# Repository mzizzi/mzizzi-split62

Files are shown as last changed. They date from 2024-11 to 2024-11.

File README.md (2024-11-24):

# split62

My take on a low profile split keyboard. 

* [x] Low profile choc 1350 switches
* [x] Hot swappable
* [x] Split layout
* [x] Ortholinear
* [x] Column staggered

This was a really rewarding project and I learned a bunch along the way! I hope that this 
repo and documentation help you build your own. That said...

**Disclaimer:** While the keyboard is working while I type out this readme, there may be 
errors and/or poorly designed componetents throughout this repository. Use these files 
at your own risk. Please also read through the [TODO](#TODO) section before deciding to 
use anything in this repository.

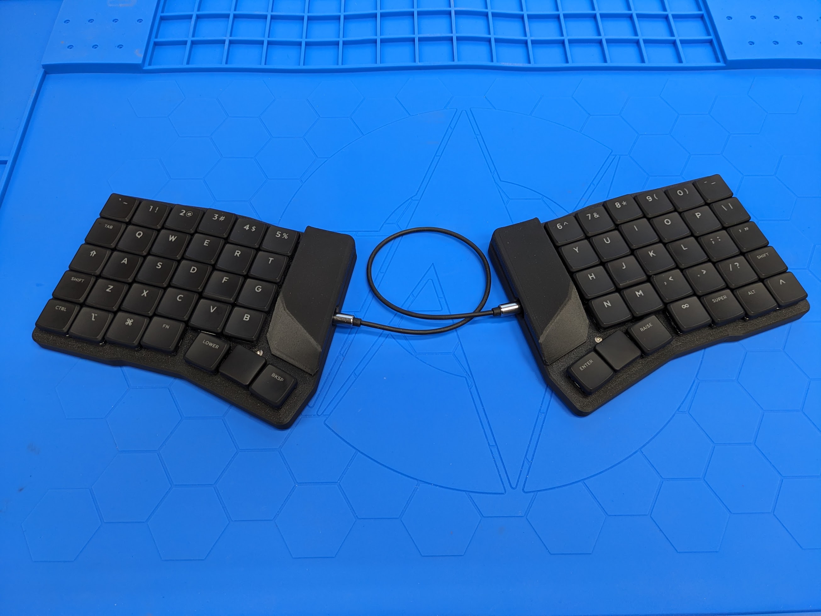
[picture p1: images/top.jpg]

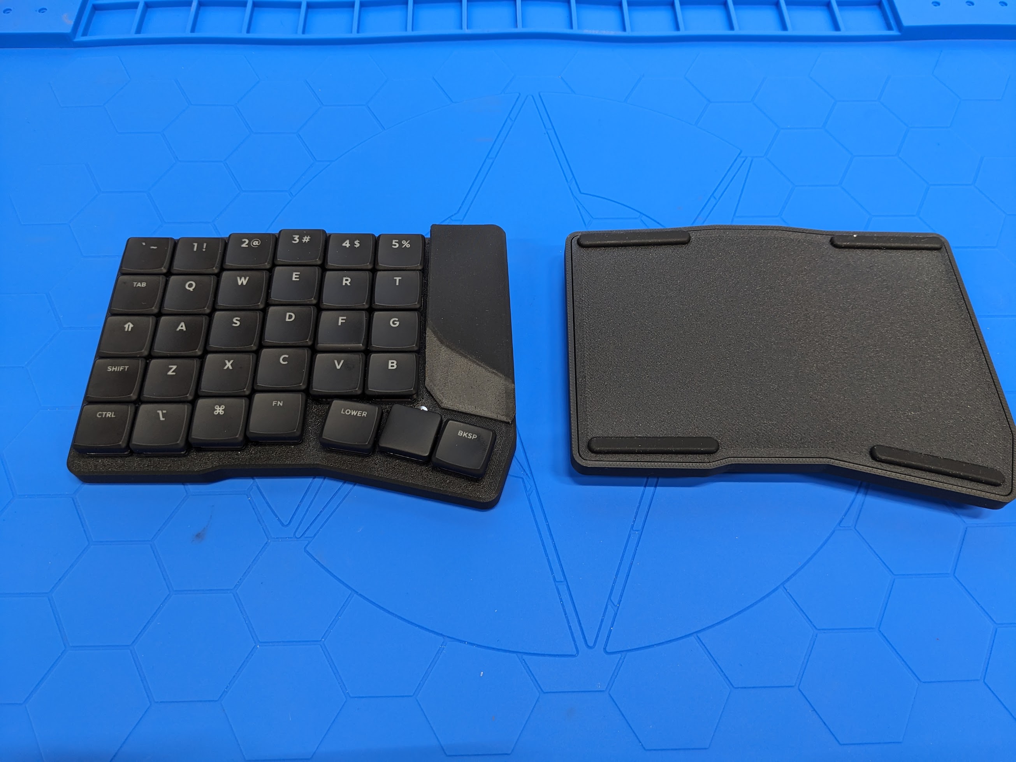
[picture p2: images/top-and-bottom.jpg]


## Firmware

This keyboard's firmware is built using QMK.

[Set up QMK](https://docs.qmk.fm/newbs_getting_started) locally and copy `qmk/keyboards/mzizzi`
 from this repository into your local qmk keyboards directory.

Connect one half of the keyboard and put the elite-pi into bootloader mode. keeb.io has excellent 
documentation on flashing firmware to the elite-pi: https://docs.keeb.io/elite-pi-guide#flashing

Enter bootloader mode (use one of the following methods):
* For a new Elite-Pi out of the packaging, it will already start in bootloader mode when plugged 
  into the computer
* Hold the Boot button (the left button) down, while pluging in the USB-C cable
* Wait for OS to detect the Elite-Pi. It will show up as a USB mass-storage device named RPI-RP2.

After the initial flash of the board you can simply hold down top innermost key (5 or 6 depending 
on the hand) while plugging in the elite-pi to make it connect in bootloader mode.

Each half of the keyboard must be flashed separately with qmk 
[handedness](https://docs.qmk.fm/features/split_keyboard#handedness-by-eeprom) flags specifying 
which side is being flashed. Both halves must be flashed:

```
qmk flash -kb mzizzi/split62 -km via -bl uf2-split-left
or
qmk flash -kb mzizzi/split62 -km via -bl uf2-split-right
```

## Configuration with via

This keyboard's firmware is compiled with support for [VIA](https://www.caniusevia.com/) which 
will allow for the keymap to be modified on the fly. The 
[via documentation](https://www.caniusevia.com/docs/specification) covers everything needed to 
get via working with the split62.

* Flash the keyboard via the instructions in this readme.
* Open https://usevia.app/ in your web browser
* Enable design mode in via settings
* Upload `qmk/keyboards/mzizzi/split62/via.json` in the design tab
* Authorize via access to the device
* Start customizing!                                                                                  |

## PCB

The PCB for this board was designed with [ergogen](https://ergogen.xyz/). I highly recommend
reading the [flatfootfox ergogen introducution](https://flatfootfox.com/ergogen-introduction/)
if you're looking to modify this board or make your own.

The PCB for this keyboard is reversible to cut down on cost of having it manufactured. Most board
manufacturers have a minimum order quantity per design (5 boards for jlcpcb). This makes for an 
interesting footprint for the elite-pi. The board is marked on either side to try and make it 
harder to accidentally install the controller socket on the wrong side.

All of the gerber files that I used to order these boards are included in the `gerbers` directory. 
Please read the [TODO](#TODO) section below before deciding whether or not to use these 
files as-is.

## Case

The case for the split62 is 3d printed. The outter shell of the case also serves as a key-plate to 
lock the choc switches into position. Ergogen is not used to generate the stls for the case.
Instead ergogen is used to generate dxfs for a "keyplate" outline. I imported that outline into
another CAD program and used it as a starting point to model the case. I printed the case on a 
bambulab x1c with 0.2mm layer height using 
[Overture matte black PLA](https://www.amazon.com/gp/product/B089S2QDHD)

## Bill of Materials

I built this keyboard for around $200 but also have a bunch of spare parts left over. 
[keeb.io](https://keeb.io/) links because they're awesome and did same day order+pickup for 
components that weren't even listed on their site!

| Item | Count | Cost | Notes |
| --- | ----- | --- | --- |
| 5x PCB | 5 | $21.00  | Only 2x needed. 5x minimum order from JLCPCB |
| 3D Printed Cases | 1 | $5.00 | Probably less if you have a printer (or know someone with a printer!) |
| Elite-Pi Controllers | 2 | $26.00  | [https://keeb.io/products/elite-pi-usb-c-pro-micro-replacement-rp2040](https://keeb.io/products/elite-pi-usb-c-pro-micro-replacement-rp2040) |
| Controller sockets | 2 | $10.00  | Not required but recommended: [https://www.amazon.com/gp/product/B07H3SK179](https://www.amazon.com/gp/product/B07H3SK179) |
| Kailh 1350 switches | 62 | $38.00  | [https://keeb.io/products/kailh-choc-low-profile-switches-v1](https://keeb.io/products/kailh-choc-low-profile-switches-v1) |
| Kailh 1350 sockets | 62 | $16.00  | [https://www.amazon.com/100Pieces-Chocolate-Switches-Accessories-Mechanical-PC/dp/B0CPVJLMDJ](https://www.amazon.com/100Pieces-Chocolate-Switches-Accessories-Mechanical-PC/dp/B0CPVJLMDJ) |
| 1N4148 SMT SOD-123 Diodes | 62 | $10.00  | [https://www.amazon.com/gp/product/B09DR5KFXM](https://www.amazon.com/gp/product/B09DR5KFXM) |
| PJ-320A TRRS jacks | 2 | $1.00 | [https://keeb.io/products/trrs-jack-3-5mm](https://keeb.io/products/trrs-jack-3-5mm) |
| Choc 1350 Keycaps | 62 | $54.00  | [https://keeb.io/products/mbk-glow-r2-choc-keycap-set](https://keeb.io/products/mbk-glow-r2-choc-keycap-set) |
| TRRS Cable | 1 | $4.00 | [https://keeb.io/products/trrs-cable?variant=50550149190](https://keeb.io/products/trrs-cable?variant=50550149190) |
| m2 screws | 8 | $7.00 | [https://www.amazon.com/Countersunk-DIN7991-Stainless-Threaded-Fasteners/dp/B0CG1PDBWN](https://www.amazon.com/Countersunk-DIN7991-Stainless-Threaded-Fasteners/dp/B0CG1PDBWN) |
| m2 threaded inserts | 8 | $8.00 | [https://www.amazon.com/gp/product/B0B8GN63S2](https://www.amazon.com/gp/product/B0B8GN63S2) |
| Rubber feet | 8 | $3.00 | [https://keeb.io/products/skuf-silicone-rubber-keyboard-feet](https://keeb.io/products/skuf-silicone-rubber-keyboard-feet) |
| Total | | $203 | 

## TODO

* Put the trrs jack closer to the side of the board. I had to cut away a few millimeters of the 
  board with a rotary tool so that the trrs connector had clearance to be fully inserted.
* Double check the trace size for 3v3 power and ground over the trrs cable. I used whatever the 
  default was without looking into how much power the rp2040 consumes. Google says that the rp2040 
  draws 20mA peak.
* More mounting holes on the PCB. A few more wouldn't hurt and would help with any warping of the
  3d printed case.
* Pull the sides of the PCB in a few mm. I didn't account for the case adding another 1-2mm.
* A better way to attach the MCU cover. This was an afterthought in v1 and attached with 
  double sided foam tape.
* Optional tenting mounts for the base of the case.
* Aluminum case

## Helpful Resources

Links to pages that helped me along the way:

* An excellent guide on using ergogen: https://flatfootfox.com/ergogen-introduction/
* qmk's documentation on a keyboard matrix and how it works:
  https://docs.qmk.fm/how_a_matrix_works
  * This article is what really made it stick for me: 
    https://www.dribin.org/dave/keyboard/one_html/
* The qmk hand wiring guide is a good introduction what you will later design a 
  pcb for: https://docs.qmk.fm/hand_wire 
* Matrix configuration: https://docs.qmk.fm/porting_your_keyboard_to_qmk#matrix-configuration
* Split keyboard layout marco: https://docs.qmk.fm/features/split_keyboard#layout-macro
* via: https://www.caniusevia.com/docs/specification

## More pictures
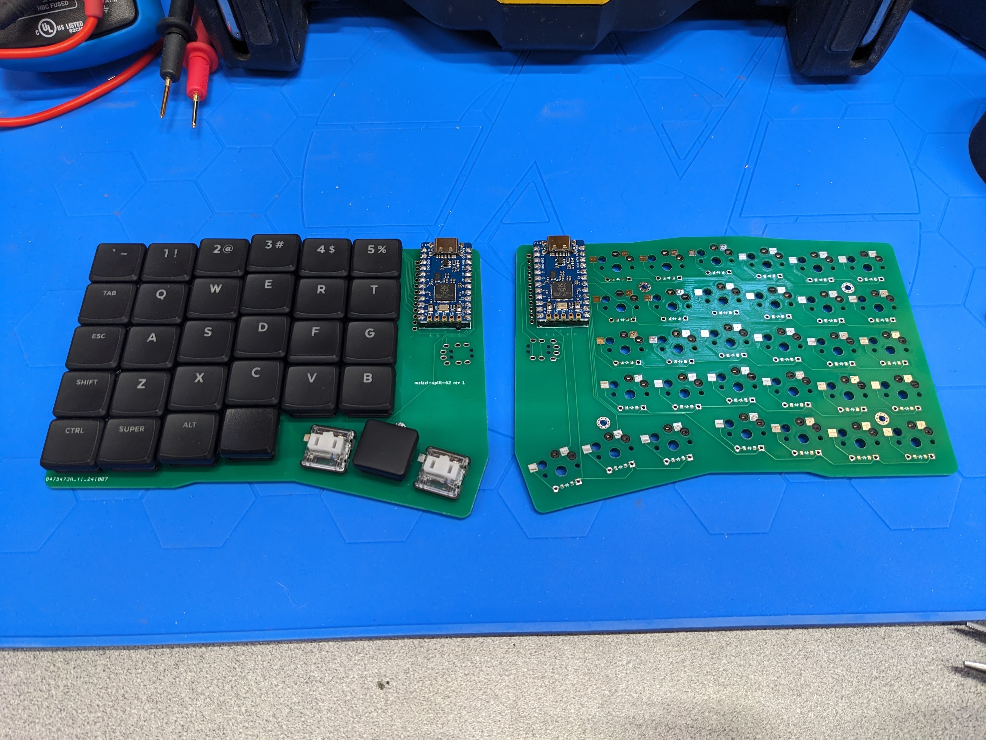
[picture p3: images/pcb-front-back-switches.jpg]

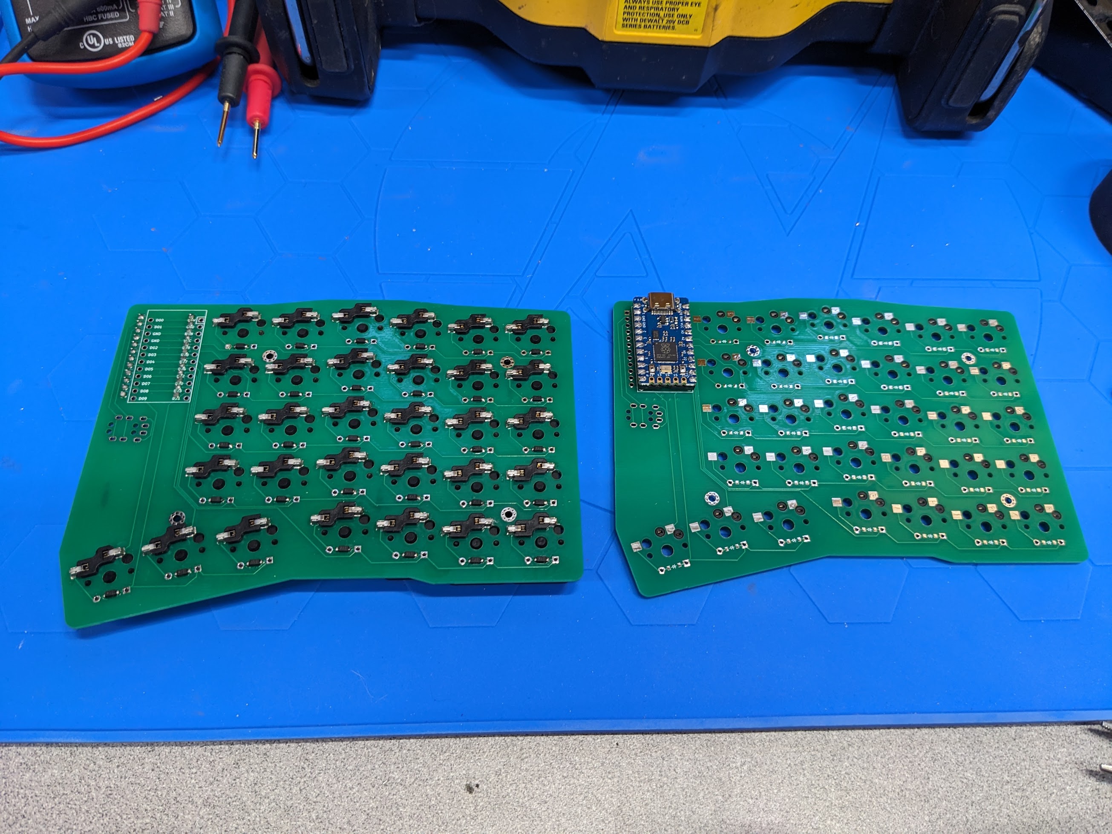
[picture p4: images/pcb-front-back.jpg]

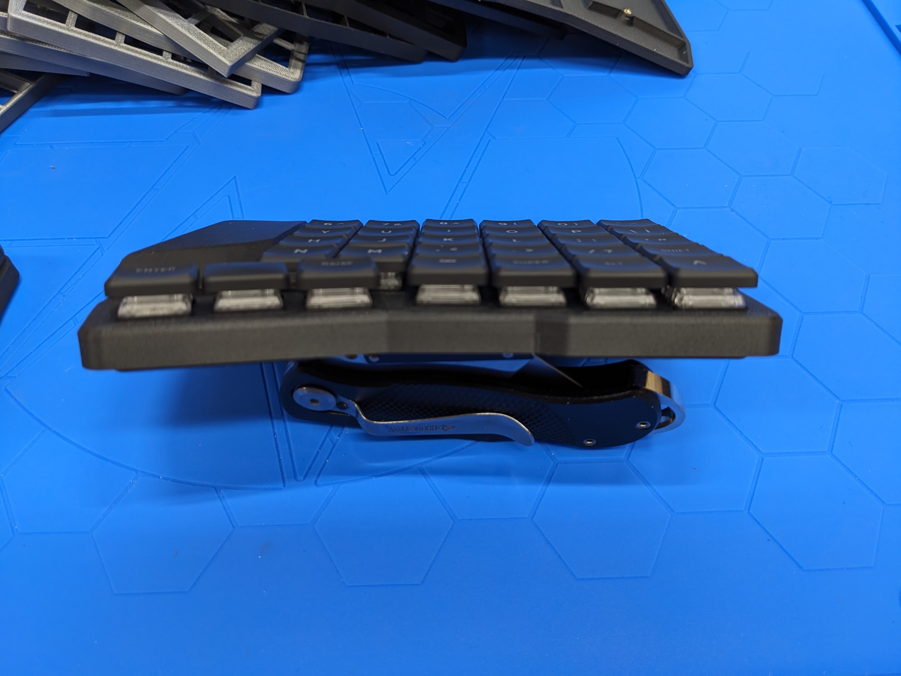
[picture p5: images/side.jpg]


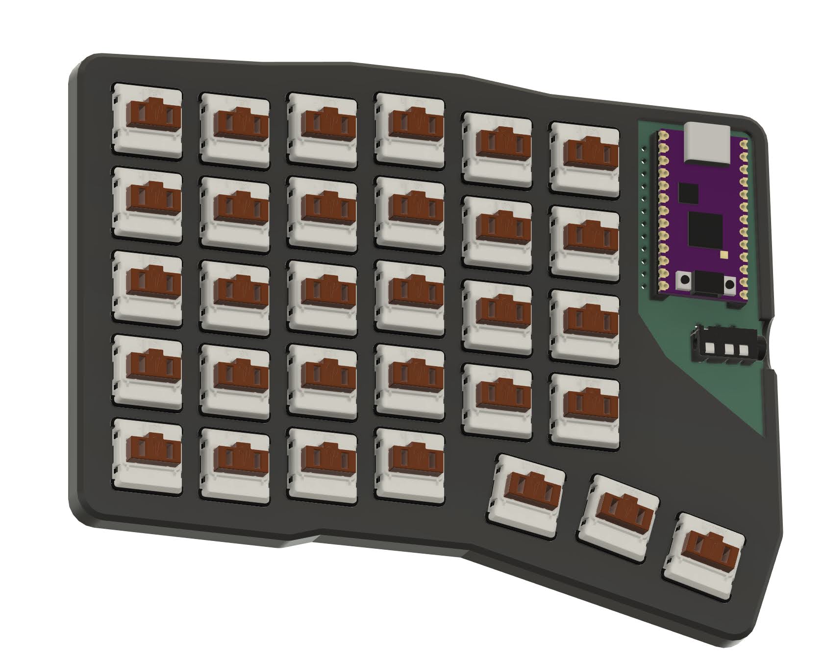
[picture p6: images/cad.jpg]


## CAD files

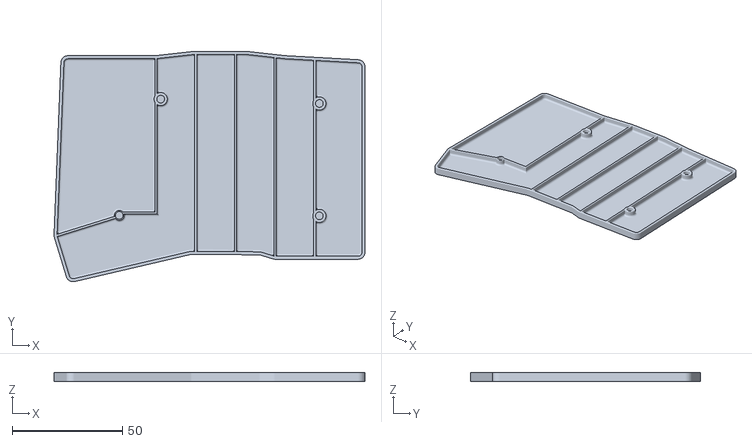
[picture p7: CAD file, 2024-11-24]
case/split62-case-bottom-right.stl
141.1 x 104.6 x 4.10

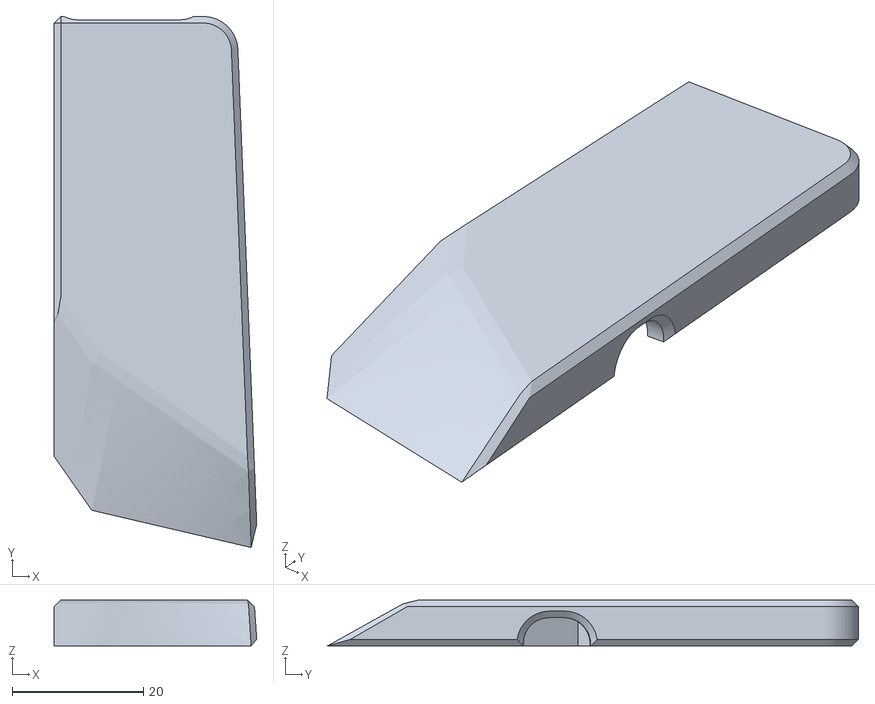
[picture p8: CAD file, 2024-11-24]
case/split62-case-cap-left.stl
30.9 x 81.0 x 7.00

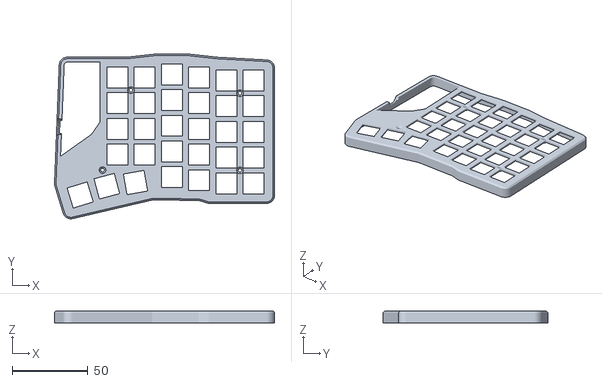
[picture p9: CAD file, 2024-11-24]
case/split62-case-top-right.stl
145.3 x 108.8 x 8.00

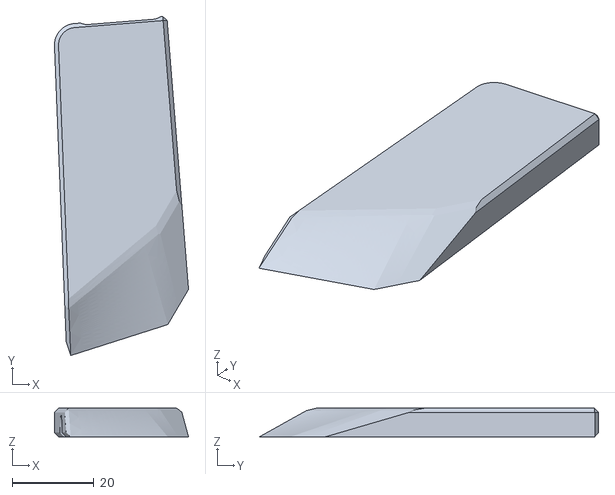
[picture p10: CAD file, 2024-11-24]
case/split62-case-cap-right.stl
32.9 x 83.1 x 7.00

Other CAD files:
case/split62-case-bottom-left.stl
case/split62-case-top-left.stl

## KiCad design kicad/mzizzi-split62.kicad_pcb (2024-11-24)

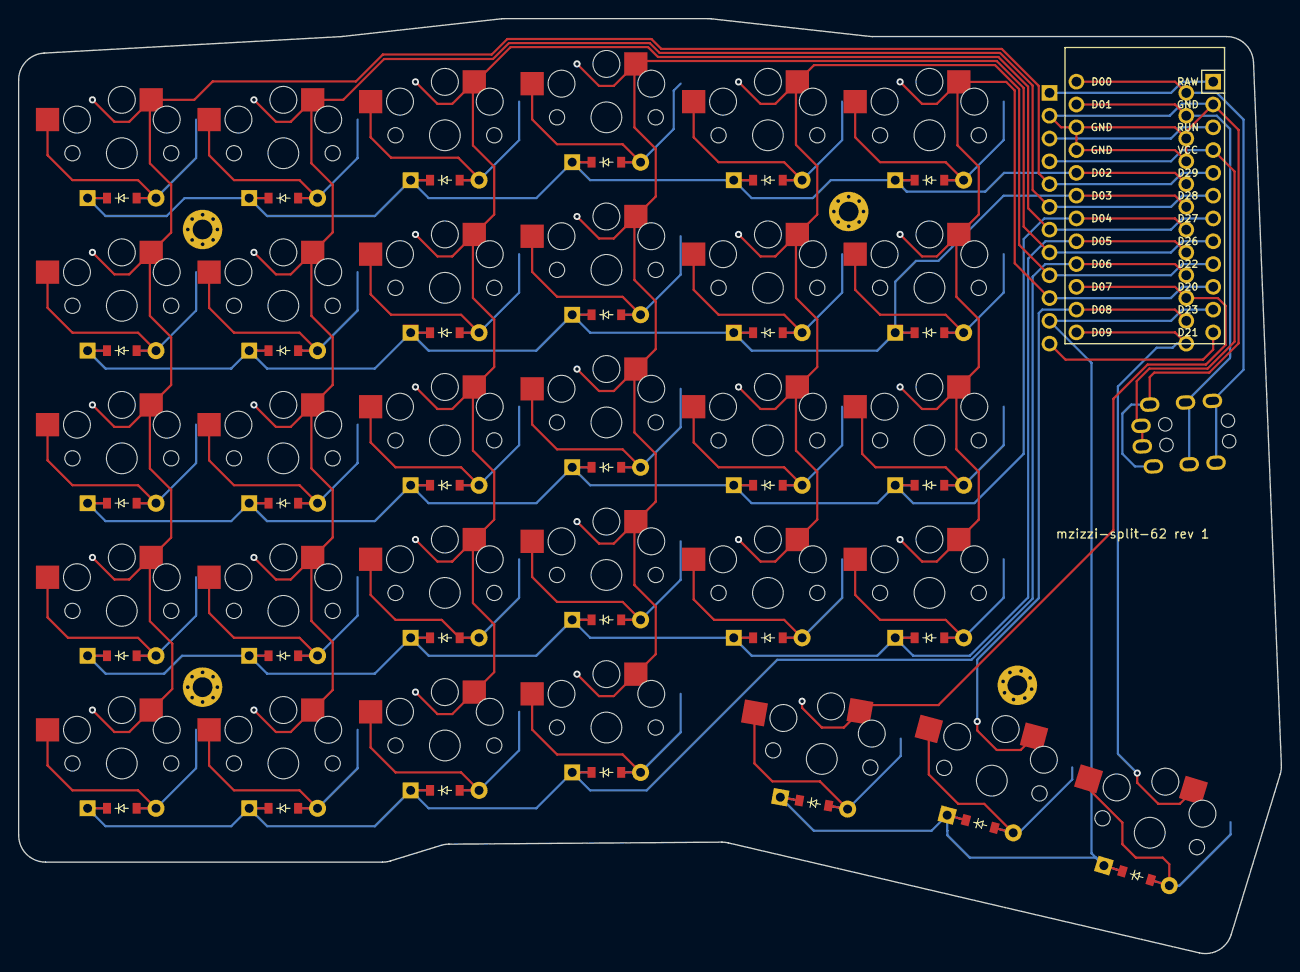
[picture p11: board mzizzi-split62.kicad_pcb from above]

Board: 2 copper layers, 140.7 x 104.2 mm, 69 parts (0 on the bottom side), 53 nets.

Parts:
D1, D2, D3, D4, D5, D6, D7, D8, D9, D10, D11, D12, D13, D14, D15, D16, D17, D18, D19, D20, D21, D22, D23, D24, D25, D26, D27, D28, D29, D30, D31: ComboDiode
MCU1, MCU2: ElitePi
S1, S2, S3, S4, S5, S6, S7, S8, S9, S10, S11, S12, S13, S14, S15, S16, S17, S18, S19, S20, S21, S22, S23, S24, S25, S26, S27, S28, S29, S30, S31: PG1350
TRRS1: TRRS-PJ-320A-dual
_1, _2, _3, _4: MountingHole_2.2mm_M2_Pad_Via

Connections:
D0: MCU1.13, MCU2.13, TRRS1.4
D1: MCU1.14, MCU2.14, TRRS1.3
D2: D5.1, D10.1, D15.1, D20.1, D24.1, D28.1, MCU1.17, MCU2.17
D3: D4.1, D9.1, D14.1, D19.1, D23.1, D27.1, MCU1.18, MCU2.18
D4: D3.1, D8.1, D13.1, D18.1, D22.1, D26.1, MCU1.19, MCU2.19
D5: D2.1, D7.1, D12.1, D17.1, D21.1, D25.1, MCU1.20, MCU2.20
D6: D1.1, D6.1, D11.1, D16.1, MCU1.21, MCU2.21
D7: MCU1.22, MCU2.22, S29.1
D8: MCU1.23, MCU2.23, S30.1
D9: MCU1.24, MCU2.24, S31.1
D20: MCU1.10, MCU2.10, S25.1, S26.1, S27.1, S28.1
D21: MCU1.12, MCU2.12
D22: MCU1.9, MCU2.9, S21.1, S22.1, S23.1, S24.1
D23: D29.1, D30.1, D31.1, MCU1.11, MCU2.11
D26: MCU1.8, MCU2.8, S16.1, S17.1, S18.1, S19.1, S20.1
D27: MCU1.7, MCU2.7, S11.1, S12.1, S13.1, S14.1, S15.1
D28: MCU1.6, MCU2.6, S6.1, S7.1, S8.1, S9.1, S10.1
D29: MCU1.5, MCU2.5, S1.1, S2.1, S3.1, S4.1, S5.1
GND: MCU1.2, MCU1.15, MCU1.16, MCU2.2, MCU2.15, MCU2.16, TRRS1.2
RAW: MCU1.1, MCU2.1
RUN: MCU1.3, MCU2.3
VCC: MCU1.4, MCU2.4, TRRS1.1
index_bottom: D21.2, S21.2
index_home: D22.2, S22.2
index_num: D24.2, S24.2
index_top: D23.2, S23.2
inner_bottom: D25.2, S25.2
inner_home: D26.2, S26.2
inner_num: D28.2, S28.2
inner_top: D27.2, S27.2
middle_bottom: D17.2, S17.2
middle_home: D18.2, S18.2
middle_mod: D16.2, S16.2
middle_num: D20.2, S20.2
middle_top: D19.2, S19.2
outer_bottom: D2.2, S2.2
outer_home: D3.2, S3.2
outer_mod: D1.2, S1.2
outer_num: D5.2, S5.2
outer_top: D4.2, S4.2
pinky_bottom: D7.2, S7.2
pinky_home: D8.2, S8.2
pinky_mod: D6.2, S6.2
pinky_num: D10.2, S10.2
pinky_top: D9.2, S9.2
ring_bottom: D12.2, S12.2
ring_home: D13.2, S13.2
ring_mod: D11.2, S11.2
ring_num: D15.2, S15.2
ring_top: D14.2, S14.2
thumbInner_thumb: D29.2, S29.2
thumbMiddle_thumb: D30.2, S30.2
thumbOuter_thumb: D31.2, S31.2
